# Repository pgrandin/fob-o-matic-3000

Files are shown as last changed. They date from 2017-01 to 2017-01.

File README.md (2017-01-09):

# fob-o-matic-3000
The Fob-O-Matic 3000

At my favorite Hackerspace, Ace Monster Toys (https://www.acemonstertoys.org/), members get 24x7 access using their fob.

When a new member wants to join the community, we need an easy way to assign them a fob. Our fobs are pre-bundled in
individual enveloppes with the sign-in instructions. This tool is a simple project that allows us to quickly get the fob
number when we are preparing a batch of keys.

The box was 3D printed and designed for this project. 

Parts list :
 - 1 Arduino Uno R3 (https://www.amazon.com/Arduino-Uno-R3-Microcontroller-A000066/dp/B008GRTSV6) 
 - 1 cheap Oled display (https://www.amazon.com/gp/product/B00O2LLT30)
 - 1 Parallax RFID reader (https://www.amazon.com/gp/product/B00B88HFPG). 

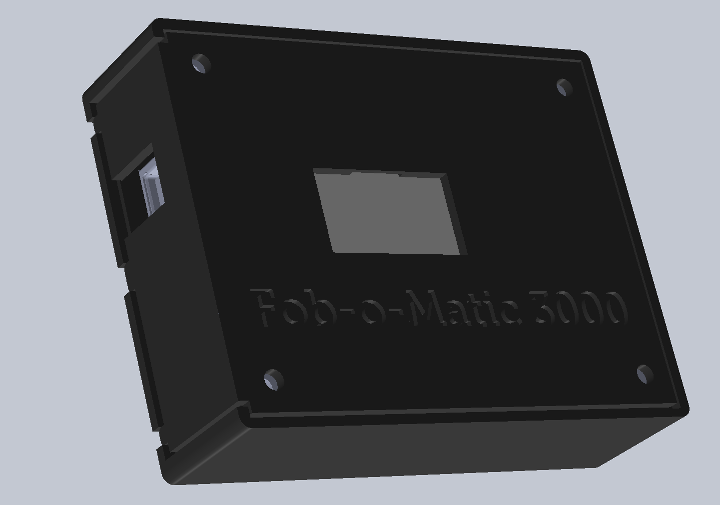
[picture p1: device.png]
The device


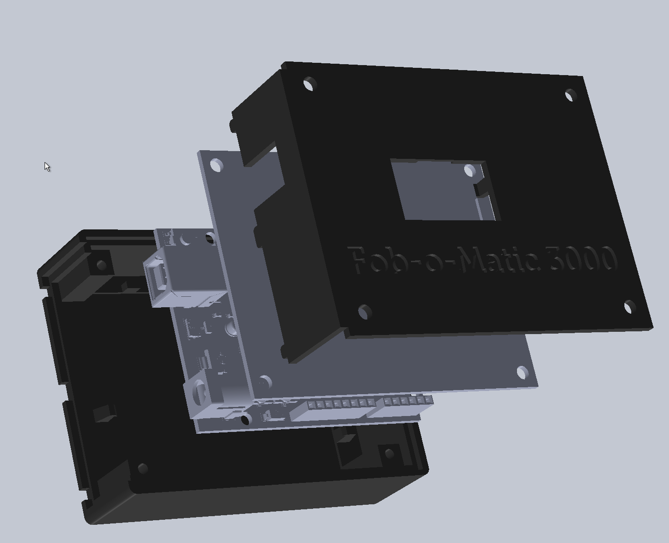
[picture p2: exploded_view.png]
Exploded view


The result:

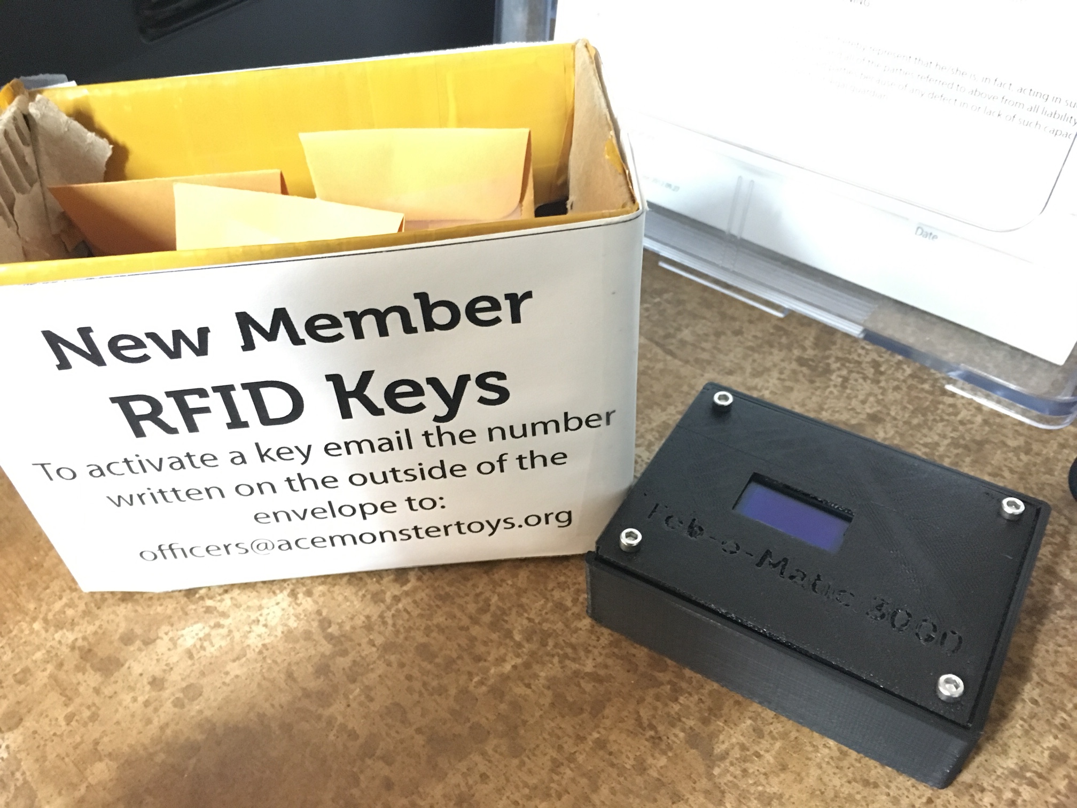
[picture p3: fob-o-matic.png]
Result


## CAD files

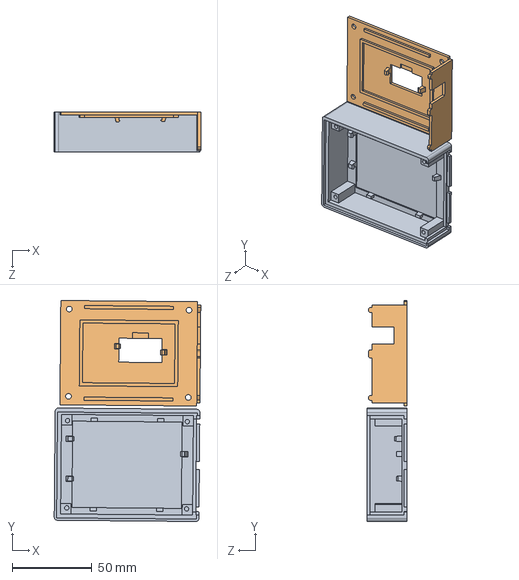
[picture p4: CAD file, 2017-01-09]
box/fob-o-matic.SLDASM
91.7 x 138.2 x 25.0 mm
bottom
top

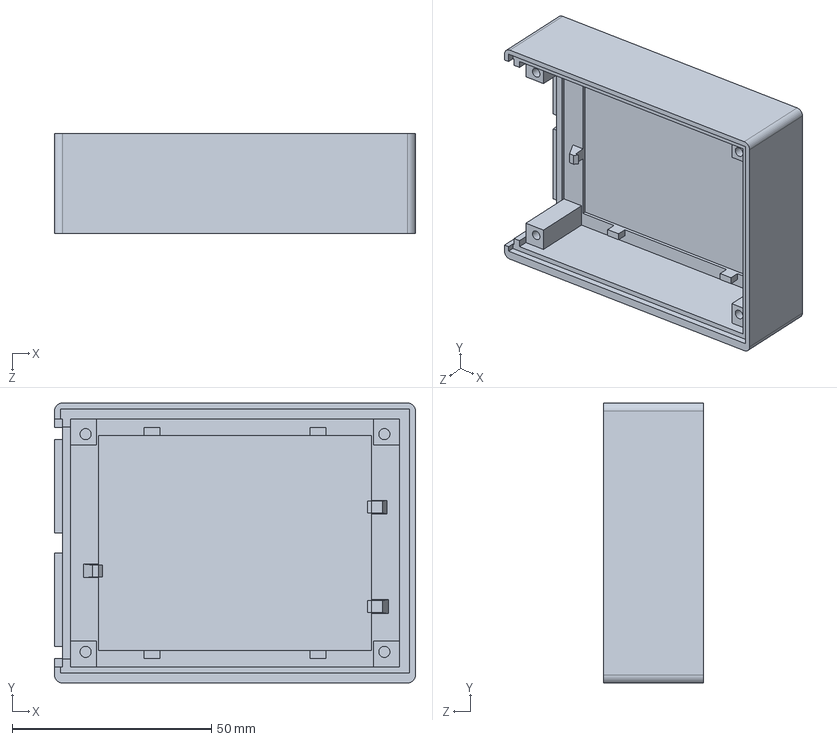
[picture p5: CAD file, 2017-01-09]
box/bottom.SLDPRT
90.5 x 70.2 x 25.0 mm

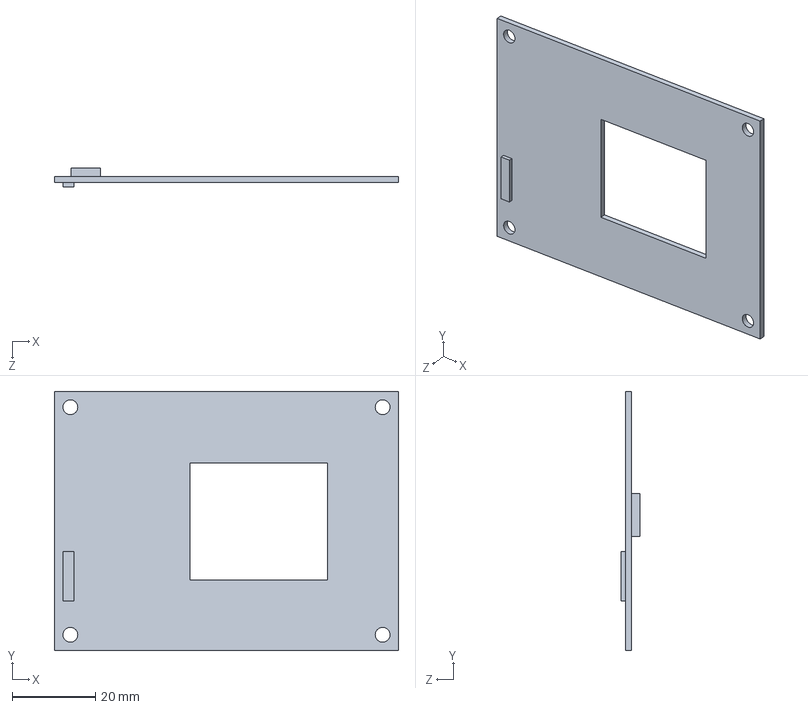
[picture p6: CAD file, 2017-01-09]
box/rfid_reader.SLDPRT
82.5 x 62.2 x 4.50 mm

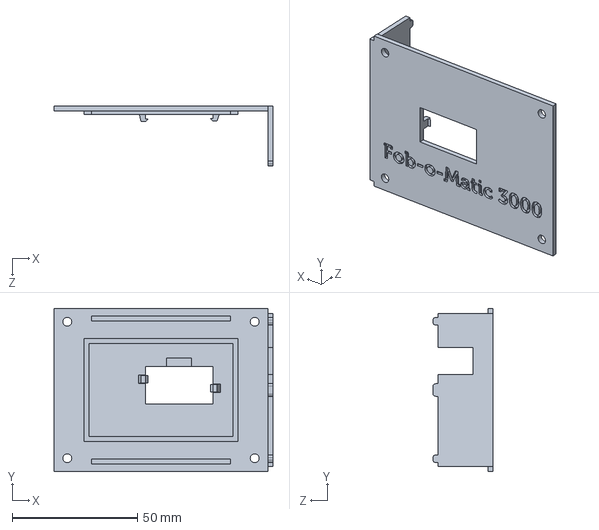
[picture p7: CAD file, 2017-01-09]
box/top.SLDPRT
87.6 x 65.3 x 24.0 mm

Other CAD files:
box/bottom.STL
box/top.STL

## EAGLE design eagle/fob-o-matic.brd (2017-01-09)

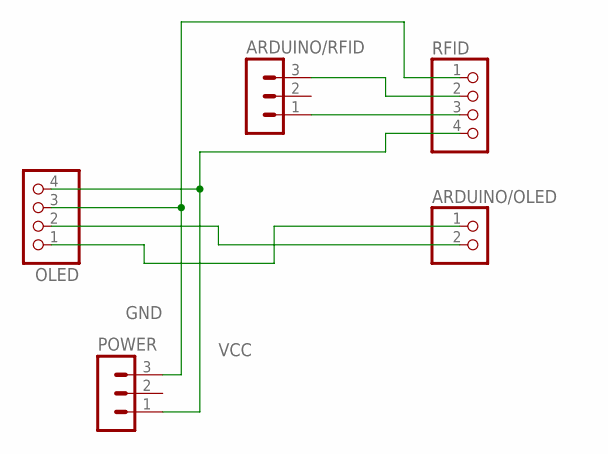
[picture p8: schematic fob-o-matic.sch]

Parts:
ARDUINO/OLED: PINHD-1X2; 1X02
ARDUINO/RFID: MA03-1
OLED: PINHD-1X4/90; 1X04/90
POWER: MA03-1
RFID: PINHD-1X4/90; 1X04/90

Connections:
/ENABLE: ARDUINO/RFID.1, RFID.3
GND: OLED.3, POWER.3, RFID.1
RX: ARDUINO/RFID.3, RFID.2
SCL: ARDUINO/OLED.2, OLED.2
SDA: ARDUINO/OLED.1, OLED.1
VCC: OLED.4, POWER.1, RFID.4

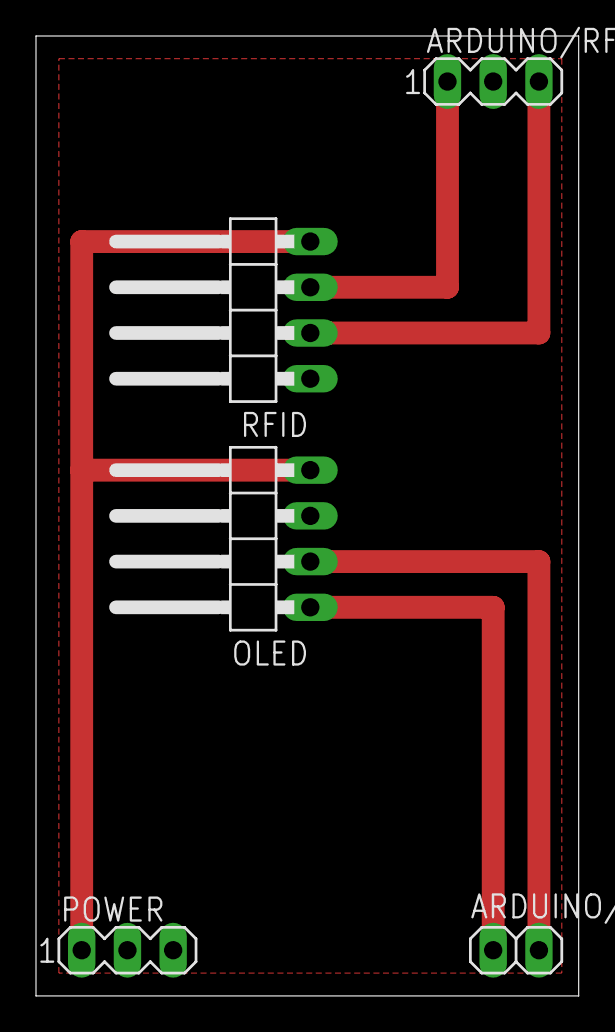
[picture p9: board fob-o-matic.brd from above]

Board: 2 copper layers, 30.1 x 53.3 mm, 5 parts (0 on the bottom side), 6 nets.

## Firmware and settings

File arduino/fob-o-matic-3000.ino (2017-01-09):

#include <SPI.h>
#include <Wire.h>
#include <Adafruit_SSD1306.h>

#define OLED_RESET 4
Adafruit_SSD1306 display(OLED_RESET);

int  val = 0; 
char code[10]; 
int  bytesread = 0; 

void setup()   {
  display.begin(SSD1306_SWITCHCAPVCC, 0x3C);  // initialize with the I2C addr 0x3C (for the 128x32)
  display.clearDisplay();
  display.setTextSize(1);
  display.setTextColor(WHITE);
  display.setCursor(0,0);
  display.println("  Fob-o-Matic 3000");
  display.println("");
  display.println(" Scan the first fob");
  display.display();
  
  Serial.begin(2400);       // RFID reader SOUT pin connected to Serial RX pin at 2400bps 
  pinMode(2,OUTPUT);        // Set digital pin 2 as OUTPUT to connect it to the RFID /ENABLE pin 
  digitalWrite(2, LOW);     // Activate the RFID reader

}


void loop() {
 if(Serial.available() > 0) {           // if data available from reader 
    if((val = Serial.read()) == 10) {   // check for header 
      bytesread = 0; 
      while(bytesread<10) {              // read 10 digit code 
        if( Serial.available() > 0) { 
          val = Serial.read(); 
          if((val == 10)||(val == 13)) { // if header or stop bytes before the 10 digit reading 
            break;                       // stop reading 
          } 
          code[bytesread] = val;         // add the digit           
          bytesread++;                   // ready to read next digit  
        } 
      } 
      if(bytesread == 10) {              // if 10 digit read is complete 
        digitalWrite(2, HIGH);                 // deactivate the RFID reader for a moment so it will not flood
        display.clearDisplay();
        display.setTextSize(2);
        display.setCursor(0,10);
        display.println(code);
        display.display();

      } 
      bytesread = 0; 
      delay(5000);                            // wait for a bit 
      digitalWrite(2, LOW);                  // Activate the RFID reader
      display.clearDisplay();
      display.setTextSize(1);
      display.setCursor(0,0);
      display.println("Ready for next fob...");
      display.display();
    } 
  }
}
